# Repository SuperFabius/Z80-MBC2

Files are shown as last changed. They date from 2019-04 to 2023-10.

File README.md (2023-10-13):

# Z80-MBC2

The Z80-MBC2 is an easy to build Z80 SBC (Single Board Computer). It is the "evolution" of the Z80-MBC (https://hackaday.io/project/19000-a-4-4ics-z80-homemade-computer-on-breadboard), with a SD as "disk emulator" and with a 128KB banked RAM for CP/M 3 (but it can run CP/M 2.2, QP/M 2.71, UCSD Pascal and others).

It has an optional on board 16x GPIO expander, and uses common cheap add-on modules for the SD and the RTC options. It has an "Arduino heart" using an Atmega32A as EEPROM and "universal" I/O emulator (so a "legacy" EPROM programmer is not needed).

It is a complete development "ecosystem", and using the iLoad boot mode it is possible cross-compile, load and execute on the target an Assembler or C program (using the SDCC compiler) with a single command (like in the Arduino IDE). 

Project page: https://hackaday.io/project/159973-z80-mbc2-4ics-homemade-z80-computer

Latest IOS revision: IOS S220718-R290823

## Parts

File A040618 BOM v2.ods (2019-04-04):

Reference | Package | Quantity | Value | Notes
C1,C2,C5,C6,C8,C9,C12 | C_Disc_D3_P2.5 | 7 | 0.1uF
C10 | C_Disc_D3_P2.5 | 1 | 0.1uF
C3,C4 | C_Disc_D3_P2.5 | 2 | 22pF
C7,C11 | C_Radial_D6.3_L11.2_P2.5 | 2 | 100uF | 16V
D1 | LED-3MM | 1 | HALT | Red
D11 | LED-3MM | 1 | SD | Red
D2 | LED-3MM | 1 | DMA | White
D3 | LED-3MM | 1 | IO_OP | White
D4 | LED-3MM | 1 | IOS | Green
D5 | LED-3MM | 1 | USER | Blue
D6,D10 | D4 | 2 | 1N4148
D7,D8,D9 | D4 | 3 | 1N5817
J1 | Pin_Header_Straight_1x04 | 1 | IOEXP
J2 | Pin_Header_Straight_1x08 | 1 | SERIAL
J3 | IDC_PCB_3x2 Male | 1 | ICSP
J4 | JST_XH 02x2.50mm | 1 | AUX_P | Not populated
J5 | Pin_Header_Straight_1x06 Female | 1 | RTC_MOD
J6 | Pin_Header_Straight_1x06 Female | 1 | SD_MOD
J7 | Pin_Header_Straight_2x10 | 1 | GPIO
Q2,Q1 | TO-92 | 2 | 2N2907
R1,R7 | R4 | 2 | 680 | 1/4 W 5%
R10,R12 | R4 | 2 | 390 | 1/4 W 5%
R11,R3,R4,R8,R9,R14,R15,R21 | R4 | 8 | 10k | 1/4 W 5%
R13 | R4 | 1 | 39 | 1/4 W 5%
R17,R18 | R4 | 2 | 4k7 | 1/4 W 5%
R19 | R4 | 1 | 1k2 | 1/4 W 5%
R2,R16 | R4 | 2 | 1k | 1/4 W 5%
R20 | R4 | 1 | 330 | 1/4 W 5%
R5 | R4 | 1 | 10K | 1/4 W 5%
R6 | R4 | 1 | 1K | 1/4 W 5%
RN1,RN2 | Resistor_Array_SIP9 | 2 | 10k x8
SW1 | SW_PUSH_SMALL | 1 | USER | 6x6x5mm
SW2 | SW_PUSH_SMALL | 1 | RESET | 6x6x5mm
U1 | DIP-14 with socket | 1 | 74HC00
U2 | DIP-40 with socket | 1 | Z84C0008 (CMOS)
U3 | DIP-40 with socket | 1 | ATMEGA32A-PU
U4 | DIP-32 with socket | 1 | TC551001-70
U5 | DIP-28 with socket | 1 | MCP23017
Y1 | HC-49V | 1 | 16MHz

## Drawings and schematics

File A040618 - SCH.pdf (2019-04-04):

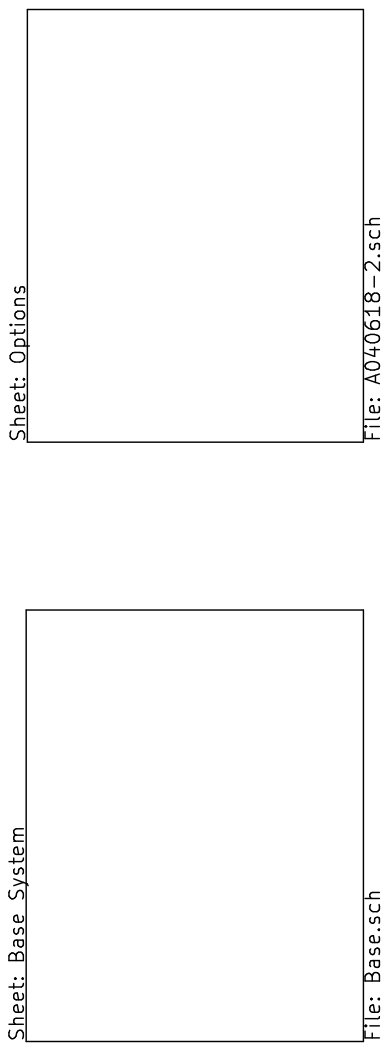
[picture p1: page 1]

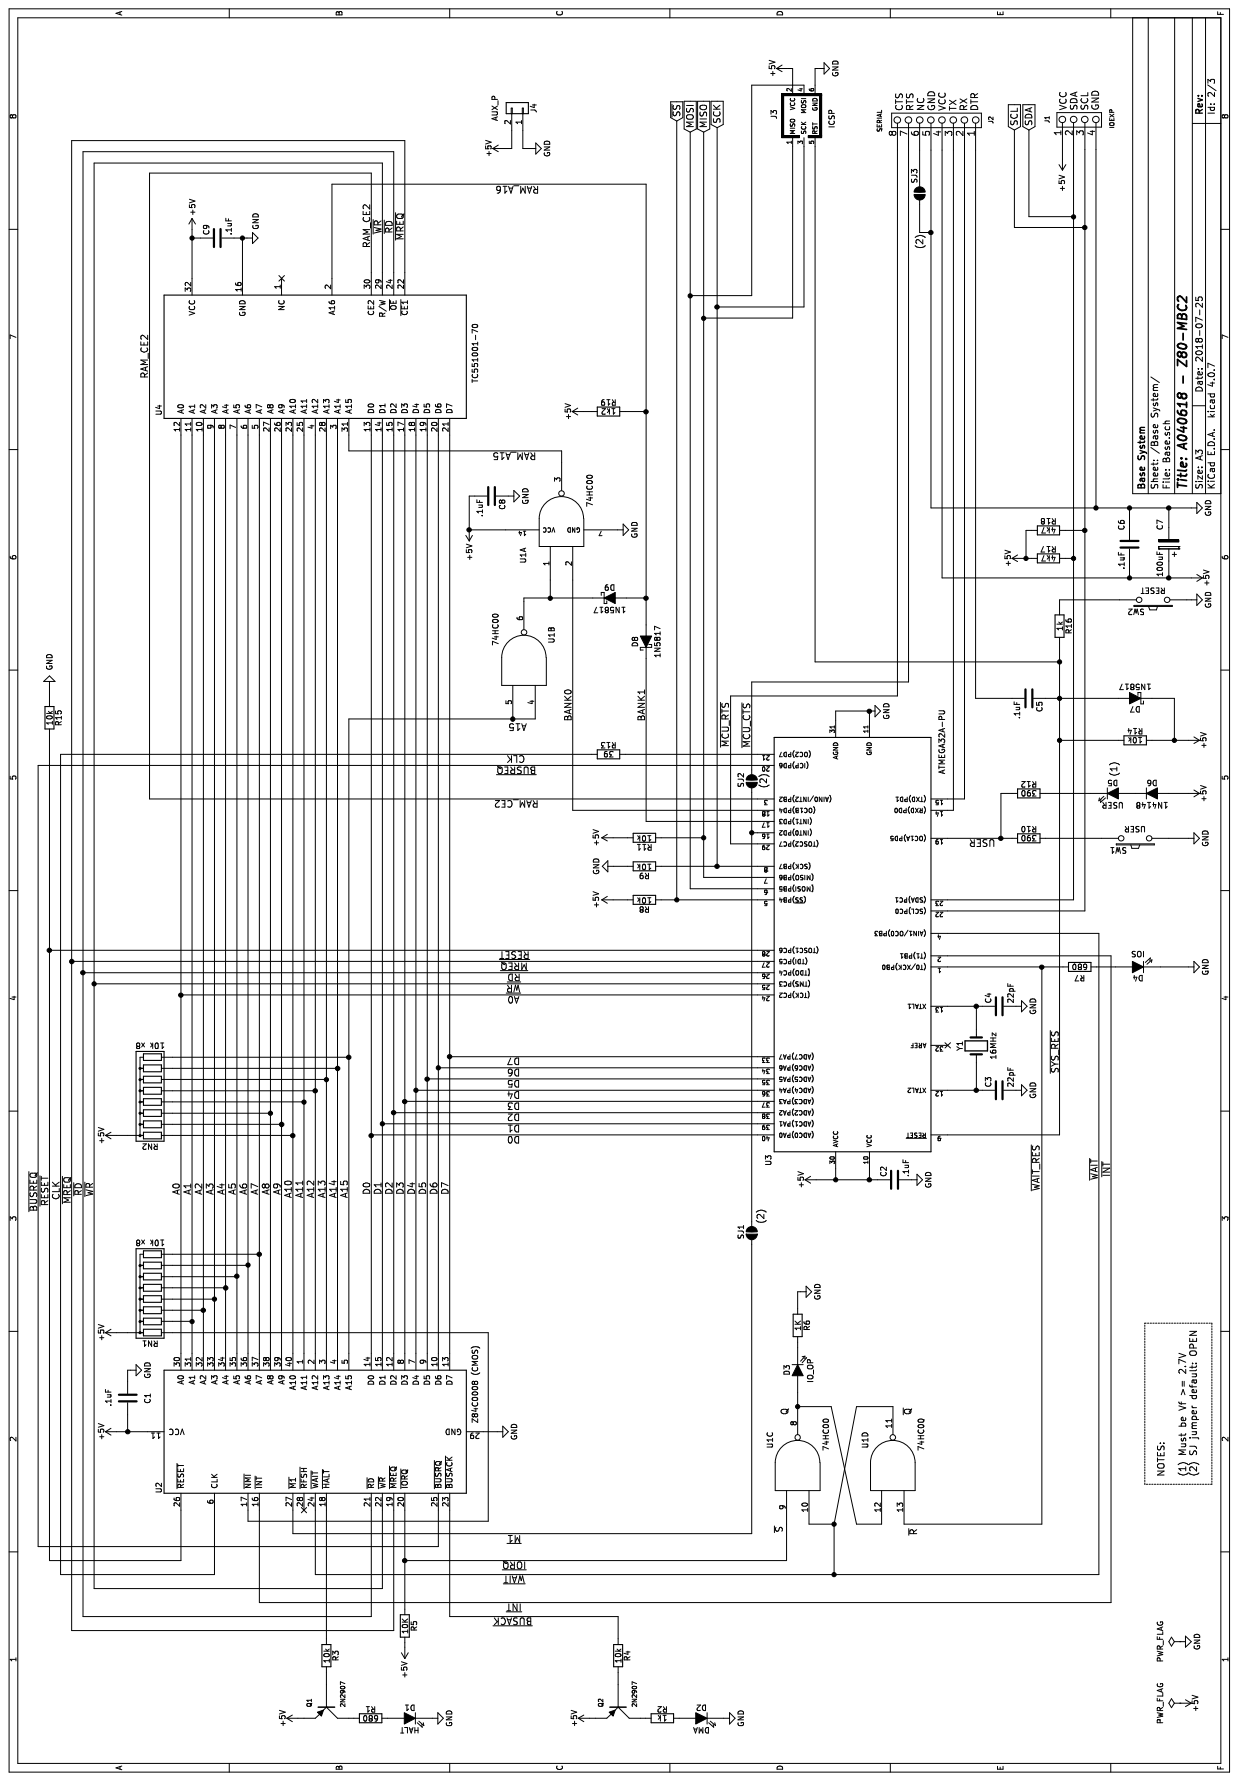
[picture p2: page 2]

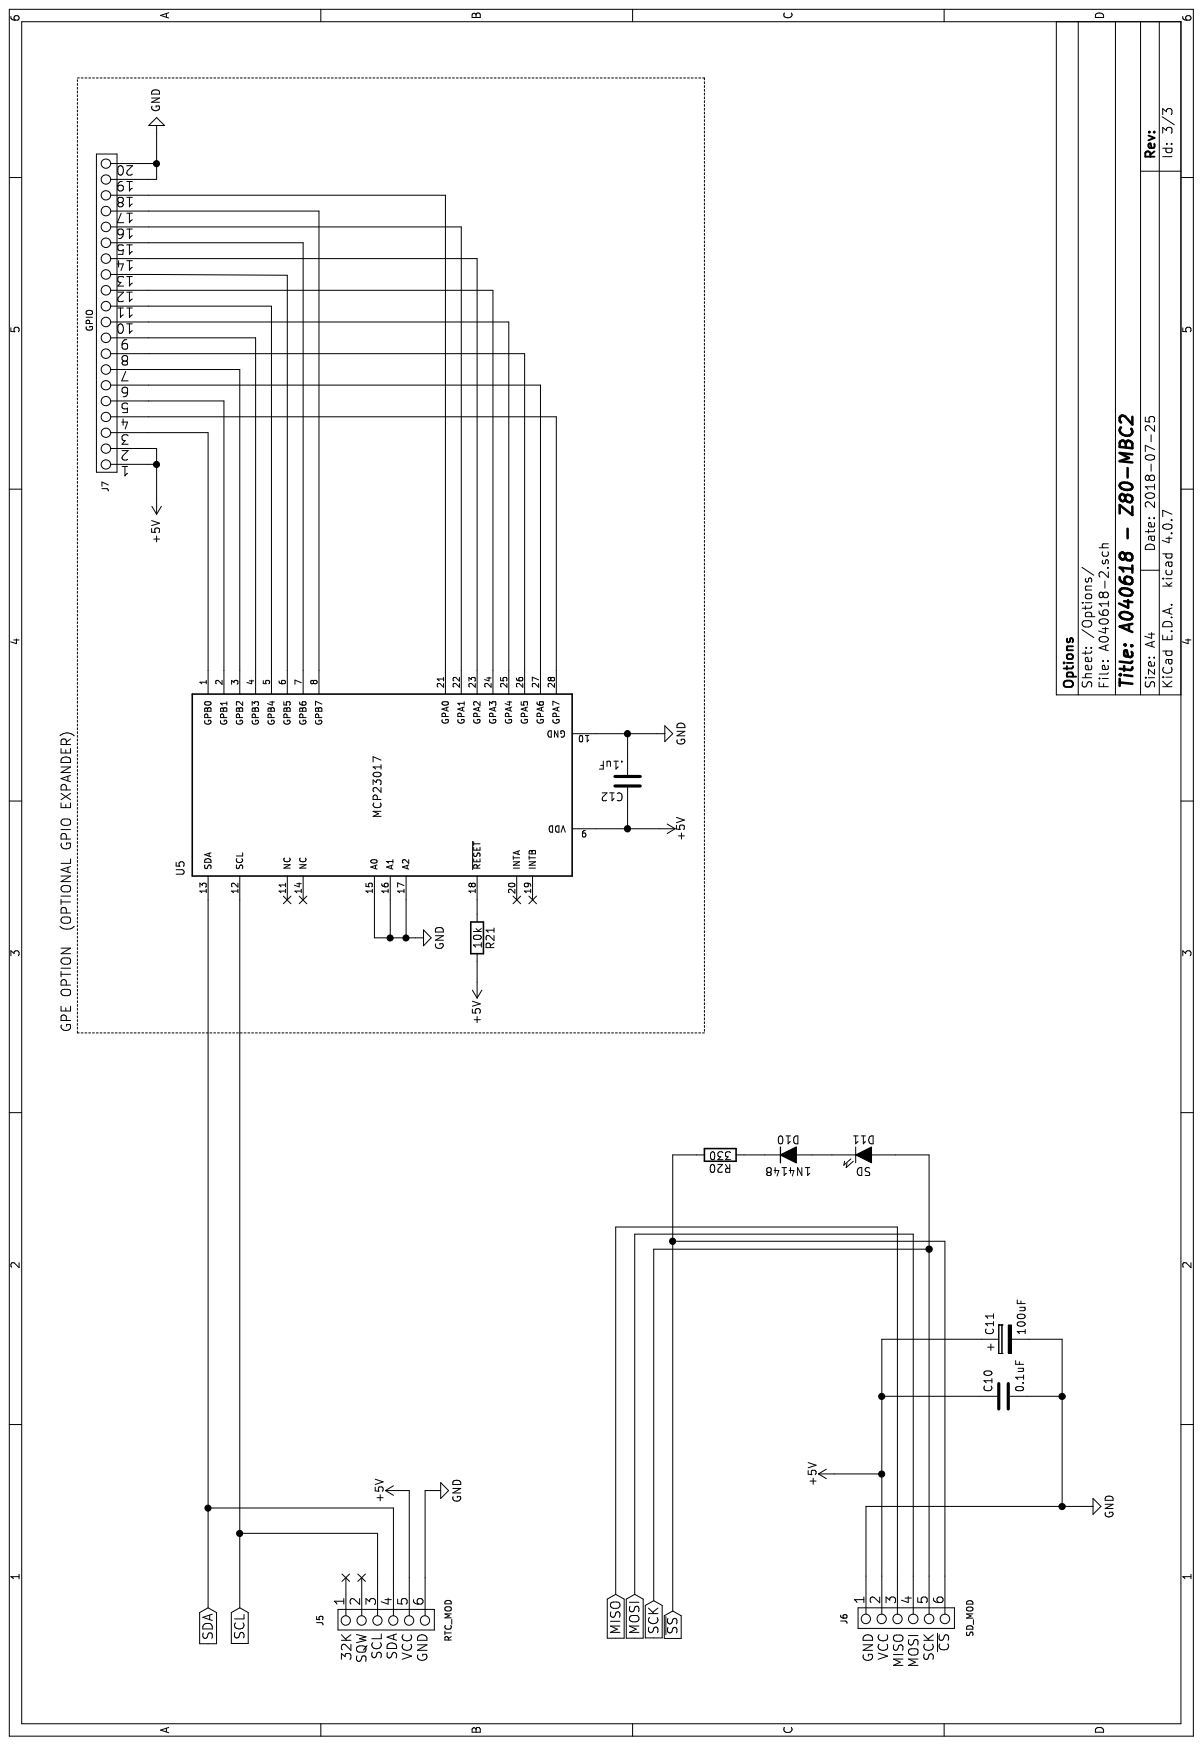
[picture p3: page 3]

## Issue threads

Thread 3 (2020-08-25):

Suitable for automated benchmark execution?

spth, 2020-08-25:
Hello, I am looking for an SBC that can be easily programmed from a host system and interface with that host system via a serial connection. This should not require any mechanic interaction (i.e. no plugging / unplugging / EPROM insertion, etc).

Basically, I want to use it as one can use modern development boards for microcontrollers.

Will this work with the Z80-MBC2? If yes, is where can I find the relevant documentation?

Background: The SDCC compiler has various backends. To track code size and performance regressions, benchmarks are compiled with new SDCC revisions and executed on STM8 and MCS-51 boards (resulting in the graphs at https://sourceforge.net/p/sdcc/code/HEAD/tree/trunk/sdcc-extra/historygraphs/).

However, currently no z80-related port is tested that way (despite Z80/GameBoy/Z180 retrocomputing being an important use case for SDCC). So I'm looking for a well-documented SBC that uses a Z80 or related to close that gap.

SuperFabius, 2020-08-25:
Hi, yes it can be done with the Iload boot mode.
This is documented for the previous version (Z80-MBC) here with SDDC: https://hackaday.io/project/19000-a-4-4ics-z80-homemade-computer-on-breadboard/log/53121-an-automated-c-language-toolchain

With the Z80-MBC2 you have to use the S190818_crt0.s file included in the SD image in the /src folder (https://cdn.hackaday.io/files/1599736844284832/SD-S220718-R240620-v1.zip).

In the same folder there is an utility (Vidit - S180818.c) written using SDDC. You can use this source file to test the automated toolchain.

bigjohnson, 2020-08-25:
I went to [https://hackaday.io/project/19000-a-4-4ics-z80-homemade-computer-on-breadboard/log/53121-an-automated-c-language-toolchain](url) and did not find the file section with the bat files, please can tell us where download them?
Thanks.

Alberto

SuperFabius, 2020-08-25:
The mentioned Files section is here: https://hackaday.io/project/19000/files

The .bat files are here: https://cdn.hackaday.io/files/19000812896000/C_batch.zip

bigjohnson, 2020-08-25:
Many thanks!

spth, 2020-08-28:
Hmm, for benchmarking, I'd also need a timer. Any recommendations? Just use a Z80-CTC like Zilog recommended back when the Z80 was new? Are they still available?

SuperFabius, 2020-08-29:
Hi, you can use a special IOS version that implements a 10Hz (100ms) sytem tick IRQ.
See here: https://github.com/SuperFabius/Z80-MBC2/blob/master/DEVEL/S220718-R120519_IOS-Z80-MBC2_DEVEL3.ino
You could activate the Systick IRQ generation at line 281 and write the code to use the Z80 INTR ISR to act as a timing IRQ.
But please note that if you activate by default the Systick IRQ at line 281, this IRQ will be always enabled from the beginning, so all the Z80 boot modes will not work any more (Iload too) because they do not use it.
So I can add a new Opcode (a virtual I/O device/register) to enable it from the Z80 side, so you can activate it from your custom program (or custom crt0) at the right moment.
In this way you don't need any new HW because the timer is emulated by the Atmega32.
Adding a new Opcode to do this is an easy task, so if is ok for you I can add it quickly.
So let me know...

SuperFabius, 2020-08-29:
...or I can just add a new Opcode to act as a start/stop timer without any IRQ, so the benchmark will not be affected by the time used to serve the Sysytick IRQ.

spth, 2020-08-30:
Thanks.

I've ordered a kit, and will look into it once I've assembled it.

An interrupt would be fine, though I'm not sure a 10 Hz resolution is enough. On the other boards, I use 1 kHz resolution (just using the 16-bit timer directly on STM8, via an interrupt on C8051).
I don't think the interrupt overhead would make a big difference (and after all the main purpose of the benchmarks is to compare to the same benchmark compiled using a different compiler revision, so any interrupt overhead doesn'T affect the comparison - unless we have a serious interrupt overhead regression, which is something we would want to show up in the benchmarks).

SuperFabius, 2020-08-31:
Hi,
I've uploaded [**here**](https://github.com/SuperFabius/Z80-MBC2/tree/master/DEVEL) a custom version [S220718-R120519_IOS-Z80-MBC2_DEVEL4.ino](https://github.com/SuperFabius/Z80-MBC2/blob/master/DEVEL/S220718-R120519_IOS-Z80-MBC2_DEVEL4.ino) of the SW for the Atmega32 that allows to set a systick IRQ in the range of [1..255] milliseconds from the Z80 application.
To compile it with the Arduino IDE you need to put in the same directory also the others source files normally included (see [here](https://cdn.hackaday.io/files/1599736844284832/S220718-R240620_IOS-Z80-MBC2.zip)).
I've uploaded a source test file (assembler) to show how to use the new needed Opcodes (the virtual I/O commands to the Atmega32 firmware) to deal with the IRQs, as [source](https://github.com/SuperFabius/Z80-MBC2/blob/master/DEVEL/testZ80RxBlinkIRQ.asm) and [.hex executable](https://github.com/SuperFabius/Z80-MBC2/blob/master/DEVEL/testZ80RxBlinkIRQ.hex) file.
For any question feel free to ask.
Regards

spth, 2020-09-09:
Out of curiosity:

FUZIX supports the Z80-MBC2. But as a Unix, FUZIX has to implement the clock() function. I think that would also require a timer. How is is done there?

SuperFabius, 2020-09-10:
Using an IRQ (INTR signal) every 100ms. Anyway I haven't tested the last version of Fuzix on the Z80-MBC2.

spth, 2021-05-19:
After some break (got Rabbit boards to work for a similar purpose, by resurrecting OpenRabbit), I want to have another look at this. I have to admit, I didn't really do anything with the Z80-MBC2 so far (assembled it, connected the serial port, booted it, saw the messages up to "IOS: SD error 2 (NOT_READY on MOUNT operation) IOS: Check SD and press a key to repeat" and that's it. Don't have experience with avr, didn't have the hardware to change the firmware in the avr part. A few days ago, I got an Atmel-ICE basic, and hope I can use it with avrdude.

So coming back to this:
* I guess even the 10 Hz interrupt would be good enough, though a slightly higher frequency would be better.
* I'd prefer this to work without an SD card.
* What would I do with an .ino file? It looks like C source to me, so I guess I compile it with GCC for avr target then use avrdude to get the resulting firmware binary onto the Z80-MBC2?
* I guess I should try to get some "Hello, world!" or so running first, then proceed to benchmarks.
* In the end I want it fully automated: invoke a script with parameters for the compiled benchmark and the serial port used, see the output on the console (i.e. something like https://sourceforge.net/p/sdcc/code/HEAD/tree/trunk/sdcc-extra/historygraphs/execute_benchmark-stm8 for the STM8).
* The final goal is to use the Z80-MBC2 to get benchmark score graphs for SDCC revsisionc, to spot regressions in the SDCC z80 backend, likethis one for the SDCC stm8 port: https://sourceforge.net/p/sdcc/code/HEAD/tree/trunk/sdcc-extra/historygraphs/coremark-stm8-score.svg

SuperFabius, 2021-05-20:
To use the Z80-MBC2 with SDCC you doesn't need any SD. You have to set the "iLoad boot mode" from the system menu (press RST + USER, then release RST holding USER down until you see the menu).
In the SD image .zip file (/src) there is a S190818_crt0.s file ready for SDCC.

You can make a fully automated toolchain using Tera Term (or probably minicom) having a serial-USB adapter with the DTR line.

So as first step try to compile with SDCC a simple helloworld. You can give a look at "Vidit - S180818.c" (/src) too.
Just to have an idea how setup the toolchain give a look here (it is referred to the previous version):
https://hackaday.io/project/19000-a-4-4ics-z80-homemade-computer-on-breadboard/log/53121-an-automated-c-language-toolchain
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
SuperFabius, 2021-06-13:
I suggest you to use Arduino IDE to upload the compiled "sketch" as it is the easiest way to do that.

Using a "normal" programmer you have to use the "S220718-R120519_IOS-Z80-MBC2_DEVEL4.ino.with_bootloader_atmega32_16000000L.hex file" (to retain the bootloader) and manually specify the needed Fuse bits into your programming SW (Fuse bits: High Byte 0xD6, Low Byte 0xAF, Lock Byte 0xCF)

spth, 2021-06-13:
I was just about to reply to you "I've already tried that, I just get the same error text in the arduino error output window as when I invoke avrdude manually". The I noticed there is a "verbose output during upload" option in preferences, and thought I just might try it to see if I get any useful information out of it (possibly to post it here).
But when I tried to upload with verbose output enabled, it just worked!

SuperFabius, 2021-06-13:
Good! May be a bad contact somewhere or some type of conflict on the serial port...

Now the step is try to run the **IRQ_test.zip** (inside the zip there is a ready to run .HEX file to use with iLoad).

spth, 2021-06-13:
Thanks. The IRQ_test.zip works for me, but even the very simple attached C program [simpletest.tar.gz](https://github.com/SuperFabius/Z80-MBC2/files/6644098/simpletest.tar.gz) does not.

In particular, the user led never lights up. I.e. it hangs from the moment I try to enable interrupts. When I remove the "ei", the LED does light up.

SuperFabius, 2021-06-15:
Hi, I've just checked what the SYSIRQ Opcode does on the source (S220718-R120519_IOS-Z80-MBC2_DEVEL4.ino) and found this interesting note I wrote  (@ line 1641):

      // NOTE 3: The INT_ signal is always reset (set to HIGH) after this I/O operation, so you have to call it
                 always from inside the ISR (on the Z80 side) before to re-enable the Z80 IRQ again.

I completely forgot that...

So you have to call this Opcode inside the ISR also if you don't need to check which one IRQ was triggered (as in your case using only the systick), because calling SYSIRQ the INT signal is cleared.

If you don't do that the INT signal remains fixed to active (low level) and the ISR is permanently called (as you know the INT signal is "level triggered" and not "edge triggered" as NMI).

Given that, at this point you must "surround" any I/O sequence with "di/ei" to avoid that a triggered IRQ could "break" a pending "Opcode_Store/Opcode_Execute" sequence.

BTW: If you can, just for curiosity, I'd like to see you crt0 and Dhrystone.c implementation, as up to now I never used IRQ with SDCC.

spth, 2021-06-15:
Dhrystone including the crt0 is here:
https://sourceforge.net/p/sdcc/code/HEAD/tree/trunk/sdcc-extra/historygraphs/dhrystone-z80/

SuperFabius, 2021-06-15:
Thanks!!

spth, 2021-06-20:
I now have some nice looking code size graphs for [Dhrystone](https://sourceforge.net/p/sdcc/code/HEAD/tree/trunk/sdcc-extra/historygraphs/dhrystone-z80-size.svg) and [Whetstone](https://sourceforge.net/p/sdcc/code/HEAD/tree/trunk/sdcc-extra/historygraphs/whetstone-z80-size.svg), that correpsond to benchmarks version that actually run on the Z80-MBC2 (I can use gtkterm to send the file and look at the result, can even toggle DTR to reboot before trying the next benchmark).

To generate similar graphs for the score, I'd need to automate the sending of the .ihx file and getting the result. I guess I could write a C program to interface with the serial port. But maybe there is some simple way to do it with some bash script or so.

SuperFabius, 2021-06-23:
May be using a bash script + a minicom macro (not sure if gtkterm can handle macros).
This way you can automate the upload for sure, and may be the output capture too.

BTW: Inside portme.c you did on the clock():

     unsigned long clock(void)
     {
	   long ret;
 	   do
		   ret = ticks;
	   while (ret != ticks);
	   return(ret);
     }

while I was expecting something as:

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

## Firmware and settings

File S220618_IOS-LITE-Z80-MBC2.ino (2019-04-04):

/* ------------------------------------------------------------------------------

S220618 - HW ref: A040618

IOS-LITE - I/O Subsystem for Z80-MBC2 (Multi Boot Computer) - LITE Edition (No SD disk support)
(Z80 128kB RAM @ 4/8Mhz)


Notes:

1:  This SW is ONLY for the Atmega32A used as EEPROM and I/O subsystem (16MHz external oscillator).
    
2:  Tested on Atmega32A @ Arduino IDE 1.8.5.

3:  Embedded FW: S210718 uBIOS + Basic, S200718 iLoad (Intel-Hex loader),
                 Forth interpreter

4:  Utilities:   S111216 TASM conversion utility


--------------------------------------------------------------------------------- */

/* ------------------------------------------------------------------------------

CHANGELOG:


S220618           First release.


--------------------------------------------------------------------------------- */

// ------------------------------------------------------------------------------
//
// Hardware definitions for A040618 (Z80-MBC2) - Base system
//
// ------------------------------------------------------------------------------

#define   D0          24  // PA0 pin 40   Z80 data bus
#define   D1          25  // PA1 pin 39
#define   D2          26  // PA2 pin 38
#define   D3          27  // PA3 pin 37
#define   D4          28  // PA4 pin 36
#define   D5          29  // PA5 pin 35
#define   D6          30  // PA6 pin 34
#define   D7          31  // PA7 pin 33

#define   AD0         18  // PC2 pin 24   Z80 A0
#define   WR_         19  // PC3 pin 25   Z80 WR
#define   RD_         20  // PC4 pin 26   Z80 RD
#define   MREQ_       21  // PC5 pin 27   Z80 MREQ
#define   RESET_      22  // PC6 pin 28   Z80 RESET
#define   MCU_RTS_    23  // PC7 pin 29   * RESERVED - NOT USED *
#define   MCU_CTS_    10  // PD2 pin 16   * RESERVED - NOT USED *
#define   BANK1       11  // PD3 pin 17   RAM Memory bank address (High)
#define   BANK0       12  // PD4 pin 18   RAM Memory bank address (Low)
#define   INT_         1  // PB1 pin 2    Z80 control bus
#define   RAM_CE2      2  // PB2 pin 3    RAM Chip Enable (CE2). Active HIGH. Used only during boot
#define   WAIT_        3  // PB3 pin 4    Z80 WAIT
#define   SS_          4  // PB4 pin 5    SD SPI * RESERVED - NOT USED *
#define   MOSI         5  // PB5 pin 6    SD SPI * RESERVED - NOT USED *
#define   MISO         6  // PB6 pin 7    SD SPI * RESERVED - NOT USED *
#define   SCK          7  // PB7 pin 8    SD SPI * RESERVED - NOT USED *
#define   BUSREQ_     14  // PD6 pin 20   Z80 BUSRQ
#define   CLK         15  // PD7 pin 21   Z80 CLK
#define   SCL_PC0     16  // PC0 pin 22   IOEXP connector (I2C)
#define   SDA_PC1     17  // PC1 pin 23   IOEXP connector (I2C)
#define   LED_IOS      0  // PB0 pin 1    Led LED_IOS is ON if HIGH
#define   WAIT_RES_    0  // PB0 pin 1    Reset the Wait FF
#define   USER        13  // PD5 pin 19   Led USER and key (led USER is ON if LOW)

// ------------------------------------------------------------------------------
//
// Hardware definitions for A040618 GPE Option (Optional GPIO Expander)
//
// ------------------------------------------------------------------------------

#define   GPIOEXP_ADDR  0x20  // I2C module address (see datasheet)
#define   IODIRA_REG    0x00  // MCP23017 internal register IODIRA  (see datasheet)
#define   IODIRB_REG    0x01  // MCP23017 internal register IODIRB  (see datasheet)
#define   GPPUA_REG     0x0C  // MCP23017 internal register GPPUA  (see datasheet)
#define   GPPUB_REG     0x0D  // MCP23017 internal register GPPUB  (see datasheet)
#define   GPIOA_REG     0x12  // MCP23017 internal register GPIOA  (see datasheet)
#define   GPIOB_REG     0x13  // MCP23017 internal register GPIOB  (see datasheet)

// ------------------------------------------------------------------------------
//
// Hardware definitions for A040618 RTC Module Option (see DS3231 datasheet)
//
// ------------------------------------------------------------------------------

#define   DS3231_RTC    0x68  // DS3231 I2C address
#define   DS3231_SECRG  0x00  // DS3231 Seconds Register
#define   DS3231_STATRG 0x0F  // DS3231 Status Register

// ------------------------------------------------------------------------------
//
//  Libraries
//
// ------------------------------------------------------------------------------

#include <avr/pgmspace.h>                 // Needed for PROGMEM
#include "Wire.h"                         // Needed for I2C bus
#include <EEPROM.h>                       // Needed for internal EEPROM R/W

// ------------------------------------------------------------------------------
//
//  Constants
//
// ------------------------------------------------------------------------------

const byte    LD_HL        =  0x36;     // Opcode of the Z80 instruction: LD(HL), n
const byte    INC_HL       =  0x23;     // Opcode of the Z80 instruction: INC HL
const byte    LD_HLnn      =  0x21;     // Opcode of the Z80 instruction: LD HL, nn
const byte    JP_nn        =  0xC3;     // Opcode of the Z80 instruction: JP nn
const String  compTimeStr   = __TIME__;  // Compile timestamp string
const String  compDateStr   = __DATE__;  // Compile datestamp string
const byte    daysOfMonth[] = {31, 28, 31, 30, 31, 30, 31, 31, 30, 31, 30, 31};
const byte    debug         = 0;        // Debug off = 0, on = 1

const word  boot_A_StrAddr = 0x0000;// Payload A image starting address
const byte  boot_A_[] PROGMEM = {   // Payload A image (S210718 uBIOS + Basic)
  0xF3, 0xC3, 0xA8, 0x00, 0x00, 0x00, 0x00, 0x00, 0xC3, 0x91, 0x00, 0x00, 0x00, 0x00, 0x00, 0x00, 
  0xC3, 0x6A, 0x00, 0x00, 0x00, 0x00, 0x00, 0x00, 0xC3, 0x9A, 0x00, 0x00, 0x00, 0x00, 0x00, 0x00, 
  0x00, 0x00, 0x00, 0x00, 0x00, 0x00, 0x00, 0x00, 0x00, 0x00, 0x00, 0x00, 0x00, 0x00, 0x00, 0x00, 
  0x00, 0x00, 0x00, 0x00, 0x00, 0x00, 0x00, 0x00, 0x18, 0x00, 0xF5, 0xE5, 0xDB, 0x01, 0xF5, 0x3A, 
  0x43, 0x20, 0xFE, 0x3F, 0x20, 0x03, 0xF1, 0x18, 0x1C, 0x2A, 0x3F, 0x20, 0x23, 0x7D, 0xFE, 0x3F, 
  0x20, 0x03, 0x21, 0x00, 0x20, 0x22, 0x3F, 0x20, 0xF1, 0x77, 0x3A, 0x43, 0x20, 0x3C, 0x32, 0x43, 
  0x20, 0xFE, 0x30, 0x38, 0x00, 0xE1, 0xF1, 0xFB, 0xED, 0x4D, 0x3A, 0x43, 0x20, 0xFE, 0x00, 0x28, 
  0xF9, 0xE5, 0x2A, 0x41, 0x20, 0x23, 0x7D, 0xFE, 0x3F, 0x20, 0x03, 0x21, 0x00, 0x20, 0xF3, 0x22, 
  0x41, 0x20, 0x3A, 0x43, 0x20, 0x3D, 0x32, 0x43, 0x20, 0xFE, 0x05, 0x30, 0x00, 0x7E, 0xFB, 0xE1, 
  0xC9, 0xF5, 0x3E, 0x01, 0xD3, 0x01, 0xF1, 0xD3, 0x00, 0xC9, 0x3A, 0x43, 0x20, 0xFE, 0x00, 0xC9, 
  0x7E, 0xB7, 0xC8, 0xCF, 0x23, 0x18, 0xF9, 0xC9, 0x21, 0xED, 0x20, 0xF9, 0x21, 0x00, 0x20, 0x22, 
  0x3F, 0x20, 0x22, 0x41, 0x20, 0xAF, 0x32, 0x43, 0x20, 0xED, 0x56, 0xFB, 0x21, 0xF5, 0x00, 0xCD, 
  0xA0, 0x00, 0x3A, 0x44, 0x20, 0xFE, 0x59, 0x20, 0x16, 0x21, 0x2B, 0x01, 0xCD, 0xA0, 0x00, 0xCD, 
  0x6A, 0x00, 0xE6, 0xDF, 0xFE, 0x43, 0x20, 0x0F, 0xCF, 0x3E, 0x0D, 0xCF, 0x3E, 0x0A, 0xCF, 0x3E, 
  0x59, 0x32, 0x44, 0x20, 0xC3, 0x50, 0x01, 0xFE, 0x57, 0x20, 0xE4, 0xCF, 0x3E, 0x0D, 0xCF, 0x3E, 
  0x0A, 0xCF, 0xC3, 0x53, 0x01, 0x75, 0x42, 0x49, 0x4F, 0x53, 0x20, 0x2D, 0x20, 0x53, 0x32, 0x31, 
  0x30, 0x37, 0x31, 0x38, 0x20, 0x28, 0x41, 0x64, 0x61, 0x70, 0x74, 0x65, 0x64, 0x20, 0x66, 0x72, 
  0x6F, 0x6D, 0x20, 0x5A, 0x38, 0x30, 0x20, 0x53, 0x42, 0x43, 0x20, 0x62, 0x79, 0x20, 0x47, 0x2E, 
  0x20, 0x53, 0x65, 0x61, 0x72, 0x6C, 0x65, 0x29, 0x0D, 0x0A, 0x00, 0x0D, 0x0A, 0x75, 0x42, 0x49, 
  0x4F, 0x53, 0x3A, 0x20, 0x43, 0x6F, 0x6C, 0x64, 0x20, 0x6F, 0x72, 0x20, 0x77, 0x61, 0x72, 0x6D, 
  0x20, 0x73, 0x74, 0x61, 0x72, 0x74, 0x20, 0x28, 0x43, 0x2F, 0x57, 0x29, 0x3F, 0x00, 0x00, 0x00, 
  0xC3, 0x56, 0x01, 0xC3, 0xF4, 0x01, 0xDD, 0x21, 0x00, 0x00, 0xC3, 0x61, 0x01, 0x07, 0x0A, 0x7D, 
  0x11, 0x21, 0x45, 0x20, 0xF9, 0xC3, 0x9C, 0x1D, 0x11, 0x2E, 0x04, 0x06, 0x63, 0x21, 0x45, 0x20, 
  0x1A, 0x77, 0x23, 0x13, 0x05, 0xC2, 0x70, 0x01, 0xF9, 0xCD, 0x2F, 0x06, 0xCD, 0xFD, 0x0B, 0x32, 
  0xEF, 0x20, 0x32, 0x3E, 0x21, 0x21, 0x43, 0x02, 0xCD, 0x9B, 0x12, 0xCD, 0x4C, 0x06, 0xCD, 0x55, 
  0x09, 0xB7, 0xC2, 0xAA, 0x01, 0x21, 0xA2, 0x21, 0x23, 0x7C, 0xB5, 0xCA, 0xBC, 0x01, 0x7E, 0x47, 
  0x2F, 0x77, 0xBE, 0x70, 0xCA, 0x98, 0x01, 0xC3, 0xBC, 0x01, 0xCD, 0x21, 0x0A, 0xB7, 0xC2, 0xFD, 
  0x04, 0xEB, 0x2B, 0x3E, 0xD9, 0x46, 0x77, 0xBE, 0x70, 0xC2, 0x85, 0x01, 0x2B, 0x11, 0xA1, 0x21, 
  0xCD, 0xC5, 0x07, 0xDA, 0x85, 0x01, 0x11, 0xCE, 0xFF, 0x22, 0xF4, 0x20, 0x19, 0x22, 0x9F, 0x20, 
  0xCD, 0x0A, 0x06, 0x2A, 0x9F, 0x20, 0x11, 0xEF, 0xFF, 0x19, 0x11, 0x3E, 0x21, 0x7D, 0x93, 0x6F, 
  0x7C, 0x9A, 0x67, 0xE5, 0x21, 0x0C, 0x02, 0xCD, 0x9B, 0x12, 0xE1, 0xCD, 0x3E, 0x19, 0x21, 0xFD, 
  0x01, 0xCD, 0x9B, 0x12, 0x31, 0xAB, 0x20, 0xCD, 0x2F, 0x06, 0xC3, 0x48, 0x05, 0x20, 0x42, 0x79, 
  0x74, 0x65, 0x73, 0x20, 0x66, 0x72, 0x65, 0x65, 0x0D, 0x0A, 0x00, 0x00, 0x5A, 0x38, 0x30, 0x20, 
  0x42, 0x41, 0x53, 0x49, 0x43, 0x20, 0x56, 0x65, 0x72, 0x20, 0x34, 0x2E, 0x37, 0x62, 0x0D, 0x0A, 
  0x43, 0x6F, 0x70, 0x79, 0x72, 0x69, 0x67, 0x68, 0x74, 0x20, 0x28, 0x43, 0x29, 0x20, 0x31, 0x39, 
  0x37, 0x38, 0x20, 0x62, 0x79, 0x20, 0x4D, 0x69, 0x63, 0x72, 0x6F, 0x73, 0x6F, 0x66, 0x74, 0x0D, 
  0x0A, 0x00, 0x00, 0x4D, 0x65, 0x6D, 0x6F, 0x72, 0x79, 0x20, 0x74, 0x6F, 0x70, 0x00, 0xB3, 0x17, 
  0x77, 0x18, 0xC9, 0x17, 0x48, 0x20, 0x5B, 0x11, 0xE0, 0x14, 0x89, 0x11, 0x3D, 0x1A, 0x1C, 0x1B, 
  0x58, 0x16, 0x8B, 0x1A, 0x91, 0x1B, 0x97, 0x1B, 0xF8, 0x1B, 0x0D, 0x1C, 0x34, 0x15, 0x78, 0x1C, 
  0x96, 0x20, 0x0D, 0x14, 0x25, 0x12, 0xA7, 0x14, 0x1C, 0x14, 0x2D, 0x14, 0x9A, 0x1C, 0x2D, 0x1D, 
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
  };
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
void loop() 
{
  if (!digitalRead(WAIT_))
  // I/O operaton requested
  {
    if (!digitalRead(WR_))
    // I/O WRITE operation requested

    // ----------------------------------------
    // VIRTUAL I/O WRTE ENGINE
    // ----------------------------------------
    
    {
      ioAddress = digitalRead(AD0);               // Read Z80 address bus line AD0 (PC2)
      ioData = PINA;                              // Read Z80 data bus D0-D7 (PA0-PA7)
      if (ioAddress)                              // Check the I/O address (only AD0 is checked!)
      // .........................................................................................................
      //
      // AD0 = 1 (I/O write address = 0x01). STORE OPCODE.
      //
      // Store (write) an "I/O operation code" (Opcode) and reset the exchanged bytes counter.
      //
      // NOTE 1: An Opcode can be a write or read Opcode, if the I/O operation is read or write.
      // NOTE 2: the STORE OPCODE operation must always precede an EXECUTE WRITE OPCODE or EXECUTE READ OPCODE 
      //         operation.
      // NOTE 3: For multi-byte read opcode (as DATETIME) read sequentially all the data bytes without to send
      //         a STORE OPCODE operation before each data byte after the first one.
      // .........................................................................................................
      //
      // Currently defined Opcodes for I/O write operations:
      //
      //   Opcode     Name            Exchanged bytes
      // -------------------------------------------------
      // Opcode 0x00  USER LED        1
      // Opcode 0x01  SERIAL TX       1
      // Opcode 0x03  GPIOA Write     1
      // Opcode 0x04  GPIOB Write     1
      // Opcode 0x05  IODIRA Write    1
      // Opcode 0x06  IODIRB Write    1
      // Opcode 0x07  GPPUA Write     1
      // Opcode 0x08  GPPUB Write     1
      // Opcode 0xFF  No operation    1
      //
      //
      // Currently defined Opcodes for I/O read operations:
      //
      //   Opcode     Name            Exchanged bytes
      // -------------------------------------------------
      // Opcode 0x80  USER KEY        1
      // Opcode 0x81  GPIOA Read      1
      // Opcode 0x82  GPIOB Read      1
      // Opcode 0x83  SYSFLAGS        1
      // Opcode 0x84  DATETIME        7
      // Opcode 0xFF  No operation    1
      //
      // See the following lines for the Opcodes details.
      // 
      // .........................................................................................................     
      {
        ioOpcode = ioData;                        // Store the I/O operation code (Opcode)
        ioByteCnt = 0;                            // Reset the exchanged bytes counter
      }
      else
      // .........................................................................................................
      //
      // AD0 = 0 (I/O write address = 0x00). EXECUTE WRITE OPCODE.
      //
      // Execute the previously stored I/O write opcode with the current data.
      // The code of the I/O write operation (Opcode) must be previously stored with a STORE OPCODE operation.
      // .........................................................................................................
      //
      {
        switch (ioOpcode)
        // Execute the requested I/O WRITE Opcode. The 0xFF value is reserved as "No operation".
        {
          case  0x00:
          // USER LED:      
          //                I/O DATA:    D7 D6 D5 D4 D3 D2 D1 D0
          //                            ---------------------------------------------------------
          //                              x  x  x  x  x  x  x  0    USER Led off
          //                              x  x  x  x  x  x  x  1    USER Led on
          
          if (ioData & B00000001) digitalWrite(USER, LOW); 
          else digitalWrite(USER, HIGH);
        break;

        case  0x01:
          // SERIAL TX:     
          //                I/O DATA:    D7 D6 D5 D4 D3 D2 D1 D0
          //                            ---------------------------------------------------------
          //                             D7 D6 D5 D4 D3 D2 D1 D0    ASCII char to be sent to serial
          
          Serial.write(ioData);
        break;

        case  0x03:
          // GPIOA Write (GPE Option):
          //
          //                I/O DATA:    D7 D6 D5 D4 D3 D2 D1 D0
          //                            ---------------------------------------------------------
          //                             D7 D6 D5 D4 D3 D2 D1 D0    GPIOA value (see MCP32017 datasheet)
          
          if (moduleGPIO) 
          {
            Wire.beginTransmission(GPIOEXP_ADDR);
            Wire.write(GPIOA_REG);                // Select GPIOA
            Wire.write(ioData);                   // Write value
            Wire.endTransmission();
          }
        break;
        
        case  0x04:
          // GPIOB Write (GPE Option): 
          //   
          //                I/O DATA:    D7 D6 D5 D4 D3 D2 D1 D0
          //                            ---------------------------------------------------------
          //                             D7 D6 D5 D4 D3 D2 D1 D0    GPIOB value (see MCP32017 datasheet)
          
          if (moduleGPIO) 
          {
            Wire.beginTransmission(GPIOEXP_ADDR);
            Wire.write(GPIOB_REG);                // Select GPIOB
            Wire.write(ioData);                   // Write value
            Wire.endTransmission();
          }
        break;
        
        case  0x05:
          // IODIRA Write (GPE Option):
          //
          //                I/O DATA:    D7 D6 D5 D4 D3 D2 D1 D0
          //                            ---------------------------------------------------------
          //                             D7 D6 D5 D4 D3 D2 D1 D0    IODIRA value (see MCP32017 datasheet)
          
          if (moduleGPIO) 
          {
            Wire.beginTransmission(GPIOEXP_ADDR);
            Wire.write(IODIRA_REG);               // Select IODIRA
            Wire.write(ioData);                   // Write value
            Wire.endTransmission();
          }
        break;
        
        case  0x06:
          // IODIRB Write (GPE Option):
          //
          //                I/O DATA:    D7 D6 D5 D4 D3 D2 D1 D0
          //                            ---------------------------------------------------------
          //                             D7 D6 D5 D4 D3 D2 D1 D0    IODIRB value (see MCP32017 datasheet)
          
          if (moduleGPIO) 
          {
            Wire.beginTransmission(GPIOEXP_ADDR);
            Wire.write(IODIRB_REG);               // Select IODIRB
            Wire.write(ioData);                   // Write value
            Wire.endTransmission();
          }
        break;
        
        case  0x07:
          // GPPUA Write (GPE Option):
          //
          //                I/O DATA:    D7 D6 D5 D4 D3 D2 D1 D0
          //                            ---------------------------------------------------------
          //                             D7 D6 D5 D4 D3 D2 D1 D0    GPPUA value (see MCP32017 datasheet)
          
          if (moduleGPIO) 
          {
            Wire.beginTransmission(GPIOEXP_ADDR);
            Wire.write(GPPUA_REG);                // Select GPPUA
            Wire.write(ioData);                   // Write value
            Wire.endTransmission();
          }
        break;
        
        case  0x08:
          // GPPUB Write (GPIO Exp. Mod. ):
          //
          //                I/O DATA:    D7 D6 D5 D4 D3 D2 D1 D0
          //                            ---------------------------------------------------------
          //                             D7 D6 D5 D4 D3 D2 D1 D0    GPPUB value (see MCP32017 datasheet)
          
          if (moduleGPIO) 
          {
            Wire.beginTransmission(GPIOEXP_ADDR);
            Wire.write(GPPUB_REG);                // Select GPPUB
            Wire.write(ioData);                   // Write value
            Wire.endTransmission();
          }
        break;
        }
        ioOpcode = 0xFF;                // All done. Set ioOpcode = "No operation"
      }
      
      // Control bus sequence to exit from a wait state (M I/O write cycle)
      digitalWrite(BUSREQ_, LOW);                 // Request for a DMA
      digitalWrite(WAIT_RES_, LOW);               // Reset WAIT FF exiting from WAIT state
      digitalWrite(WAIT_RES_, HIGH);              // Now Z80 is in DMA, so it's safe set WAIT_RES_ HIGH again
      digitalWrite(BUSREQ_, HIGH);                // Resume Z80 from DMA
    }
    else 
      if (!digitalRead(RD_))
      // I/O READ operation requested
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
